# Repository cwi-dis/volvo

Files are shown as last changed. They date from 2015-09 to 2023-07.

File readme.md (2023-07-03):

# Volvo Design Challenge 

This repository contains software and instructions for the exhibit entered into the Volvo Design Challenge 2015 by ByBorre, with help from the CWI DIS group.

Here is a video of Borre Akkersdijk explaining the vision behind it:

[Sublime News - Volvo Design Challenge - ByBorre (YouTube)](https://youtu.be/kw6YL740Hyo)

From May 2017 until June 2023 the exhibit wass on display in the Atrium at CWI. It was dismantled and put into storage, some instructions on re-assembling it if you happen to have the hardware are in [hwsetup/readme.md](hwsetup/readme.md).

Here is an image of the exhibit on display at CWI:

volvo-exhibit-cwi

Contents:

- **hwsetup** contains minimal instructions to revive the piece. See [hwsetup/readme.md](hwsetup/readme.md).

- **production** contains the hardware and software as originall built in 2017:
	- [production/readme.txt](production/readme.txt) has terse instructions on putting everything together.
	- **production/hardware** has the schematics for the matrix touch sensor (for the volume-like pad).
	- **production/jeenode** has software for the three types of JeeNode boards: the receiver, the 4-pad sender and the matrix sender.
	- **production/receiver** has the Python script that communicates with the jeenode receiver.
	- **production/server** has the web server that connects the receiver and the visualisation.
	- There are various scripts here to run everything.
- **artwork** contains the artwork for the visualisation, see [artwork/readme.txt](artwork/readme.txt) for details.
- **jeenode_test** is an Arduino program to test the matrix-style touch interface.
- **photon_experiment** is an earlier touch experiment using a Particle Photon.

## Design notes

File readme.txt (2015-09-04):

Read a lot of pressure sensors using one Particle Photon.

Sensors are in a matrix, with a diode to decould them. See
schematic.jpg for a hardware diagram.

Each row is enabled in turn (using a digital pin pulled to ground),
and then each of the sensors for that row is read (using an analog pin).
Then we advance the row, and when we've read all we store the data in the cloud.
We've seen about 10 sets of 64 readings per second.

sensors2cloud.ino runs on the Photon. Adjust rowPins and
columnPins to the number of sensors.

sensorfromcloud.sh shows how to get the data form the cloud.

You'll need to adapt the device ID and access key.

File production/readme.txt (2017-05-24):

To build the hardware see jeenode/readme.txt and the hardware folder.

To change the visualisation see server/public (which has the HTML files,
SVG files and JavaScripts). For new artwork see ../artwork/readme.txt.

To run the software on a new machine for the first time see server/README.md.

To test things there are scripts runserver.sh, runreceiver.sh and runvisualisation.sh
here, and an overall script run.sh that tries to start everything.

===========================

This set of instructions (in progress) is for using the Raspberry Pi 2.
(Below this section are the old Karnemelk instructions.)

There is an diskimage file for this system, on maunakea, PampusMedia/Special Disk Images.

To assemble the system and configure the display for the first time:

 - Assemble the table, connect the jeenodes, power it up.
 
 - attach the big screen to dispi05 rotated 90 degress (probably clockwise).
 
 - power on dispi05, takes about 60 seconds.
 
 - configure the big display to be portrait mode with the right orientation
   by editing /boot/config.txt and adding
	framebuffer_height=1920
	framebuffer_width=1080
	display_rotate=3
  and possibly removing some NOOBS settings at the end.

 - disable screen blanking. Edit /etc/xdg/lxsession/LXDE/autostart and add
	@xset s noblank 
	@xset s off 
	@xset -dpms
	
 - Install chromium-browser
	
 - Install https://github.com/cwi-dis/igor
 - Install the igor database into ~/.igor, from https://github.com/cwi-dis/igorDatabase.volvo
 
 - Pull in the Mercurial repository for dis/jack
 - Pull in the Mercurial repository for dis/tom
 
 - Install a recent node.js, instructions at 
 	https://nodejs.org/en/download/package-manager/
 	
 - cd volvo/production/server; npm install
 
 - test the server, npm start (or use the script production/runserver.sh)
 
 - test that chromium can connect and display the visualisation,
 	production/runvisualisation.sh
   
 - Attach the JeeNode dongle. Assert it's at /dev/ttyUSB0
 
 - Install <https://github.com/cwi-dis/sensor-relay-py>
 	
 - Run the receiver with runreceiver.sh
 
 - Power down the system (press power button, select "Shut down" in the dialog).

To start the system: NOT UPDATED YET
 
 - Make sure the VGA dongle is connected, VGA is connected and the big screen is on.
 
 - Make sure the JeeNode dongle is connected.
 
 - Turn on karnemelk.
 
 - After about a minute it comes up and tries to start the whole presentation (this
   will take another half minute). If everything works you should see the following things:
   
   - The macbook screen shows a grey pattern
   
   - the JeeNode dongle flashes red LEDs
   
   - the big screen shows the demo
   
 - If anything went wrong (or takes too long) type sequences of CMD-Q, RETURN and CMD-TAB
   until the macbook screen shows the black-and-white desktop again. Then doule-click
   the "start volvo on powerup" icon and hope for the best.
   
 - Always turn of the MacBook BEFORE powering down the display or removing cables. Otherwise
   you may have to go through the "assembly" procedure again.
 
To debug the system:

 - if things don't start up:
   make sure you have connected all dongles and cables. The jeenode dongle should flash when
   it is receiving data from the sensor-jeenodes (and when the receiver progrm is running).
   Looking at the Terminal window (the frontmost is probably the most recent one) may give
   an indication of what is wrong.
   
 - if some of the sensors don't work:
   you scroll down the normal presentation screen (in Google Chrome) there is a "show debug
   console" link. Click this. You will see the output of each individual sensor. You will
   also see an error message in red if any of the jeenodes is not responding.
   
 - if the display is incorrect (wrong screen, wrong orientation):
   - repeat the "assembly" procedure.

===========================

The rest of these instructions are for using karnemelk (the white MacBook)
and the byBorre user (as it has been prepared for the Volvo presentation).

To assemble the system and configure the display for the first time:

 - Assemble the table, connect the jeenodes, power it up.
 
 - attach the VGA dongle and big screen to karnemelk
 
 - power on karnemelk, takes about 60 seconds.
 
 - it may try to start the presentation (some Terminal screens, maybe a
   fullscreen Chrome browser window). Kill everything by using
   CMD-Q (quit application), CMD-TAB (goto next application) and possibly
   NEWLINE (if there is a dialog "are you sure you want to quit")
   until only the Finder is running.
 
 - configure the big display to be portrait mode
   with the right orientation (1080x1920, 75Hz is known to work. If not
   try other refresh frequencies).
   
 - set the big display to be the primary screen.
 
 - Make sure the screen saver/power saver are off (Apple Menu -> System Preferences
   -> Power Saver, all slider to the far right).
   
 - Attach the JeeNode dongle.
 
 - Power down the system (press power button, select "Shut down" in the dialog).

To start the system:
 
 - Make sure the VGA dongle is connected, VGA is connected and the big screen is on.
 
 - Make sure the JeeNode dongle is connected.
 
 - Turn on karnemelk.
 
 - After about a minute it comes up and tries to start the whole presentation (this
   will take another half minute). If everything works you should see the following things:
   
   - The macbook screen shows a grey pattern
   
   - the JeeNode dongle flashes red LEDs
   
   - the big screen shows the demo
   
 - If anything went wrong (or takes too long) type sequences of CMD-Q, RETURN and CMD-TAB
   until the macbook screen shows the black-and-white desktop again. Then doule-click
   the "start volvo on powerup" icon and hope for the best.
   
 - Always turn of the MacBook BEFORE powering down the display or removing cables. Otherwise
   you may have to go through the "assembly" procedure again.
 
To debug the system:

 - if things don't start up:
   make sure you have connected all dongles and cables. The jeenode dongle should flash when
   it is receiving data from the sensor-jeenodes (and when the receiver progrm is running).
   Looking at the Terminal window (the frontmost is probably the most recent one) may give
   an indication of what is wrong.
   
 - if some of the sensors don't work:
   you scroll down the normal presentation screen (in Google Chrome) there is a "show debug
   console" link. Click this. You will see the output of each individual sensor. You will
   also see an error message in red if any of the jeenodes is not responding.
   
 - if the display is incorrect (wrong screen, wrong orientation):
   - repeat the "assembly" procedure.

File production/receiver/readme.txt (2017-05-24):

To be able to run this you must first install sensorrelay from <https://github.com/cwi-dis/sensor-relay-py>.

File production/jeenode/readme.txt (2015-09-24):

FSR_Borre_Reveiver is the software that runs in the jeenode with USB that is connected to the computer.
FSR_Borre_Sender runs on the 3- or 2-sensor tiles.
FSR_Borre_MatrixSender runs on the 9-sensor tile.

For each jeenode, first flash RF12Demo and set node-ID and group-ID, which are kept in EEPROM (and used by our programs).
The receiver should have id 31.

All nodes should be set to group 80. Double-check this, Jack used group 81 for debugging.

After setting id/group flash the correct software and probably label the jeenode.

The normal senders use GND (black) and Vcc (red) on Port 1,
analog inputs on ports 1 (blue), 2 (orange) and 3 (yellow) to the resistor-board.
The resistor board connects to the FSR sensors with color codes blue (1), red (2)
and yellow (3), so using a red wire in stead of the orange (don't ask:-)

The matrix sender uses the resistor/diode board described in ../hardware.

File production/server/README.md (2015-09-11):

## Sensor Relay

Publish-Subscribe architecture on top of WebSockets for relaying sensor data
from sensors to browser clients. Frontend files can be found in the folder
public/.

### Installation

In order to run the server, first make sure you have `node.js` and `npm`
installed. You should be able to get both by installing Node from your
operating system's package manager.

Once you have Node and NPM installed change into the project's root directory
and run the following command:

    $ npm install

This will install all the project's dependencies into the project's root
folder. The server is now ready to run.

### Running the application

To start the application run the following command:

    $ npm start

This will set up a WebSocket server on port 23148 and a HTTP server on
port 8080. Opening `http://localhost:8080` in a web browser will display
the visualisations and any data sent to port 23148.

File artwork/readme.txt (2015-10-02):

To prepare new artwork by Evan (saved as SVG with bitmaps inlined) do the following steps:
- Remove the preamble, everything before the <svg> tag (about 10 lines).
- Insert the content of svg-defs somewhere near the top (inside the first <g> element for example)
- Set the fill pattern of the hand segments correctly by adding
  	style="fill: url(#handfill)"
  to the polygons in group _x3C_hand_x5F_fill_x5F_group_x3E_ (which is
  inside group Hand_x5F_Action)
- Compare the result to ../production/server/public/img/volvo_graphic.svg to double
  check I haven't forgotten anything, there may be a few other IDs that need changing.
- Finally copy the new artwork to ../production/server/public/img/volvo_graphic.svg

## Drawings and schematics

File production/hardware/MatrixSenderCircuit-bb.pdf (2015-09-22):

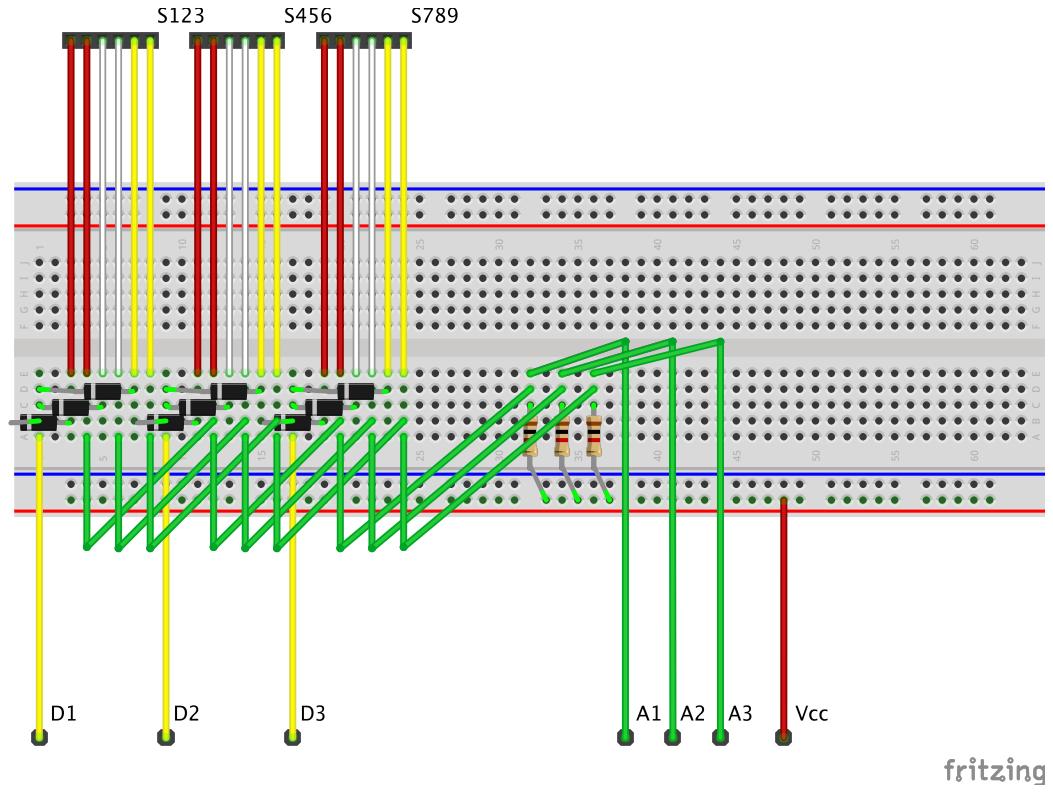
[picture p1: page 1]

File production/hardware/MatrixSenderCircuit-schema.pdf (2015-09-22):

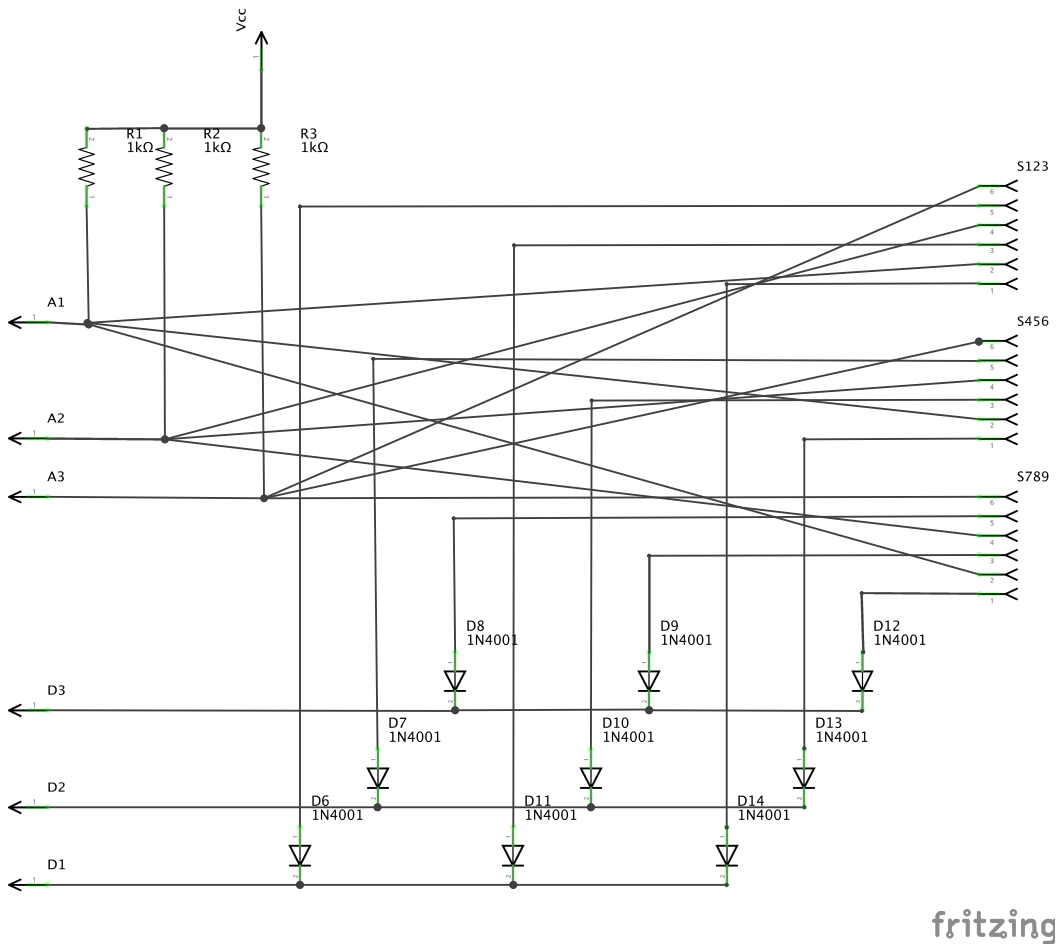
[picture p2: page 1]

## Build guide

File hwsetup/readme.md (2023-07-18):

# Reviving the Volvo hardware

These instructions (and the referenced video) come from <https://github.com/cwi-dis/volvo>, which also contains all the source code to the software, plus some schematics, background information etc.

volvo-exhibit-cwi

## Parts list
 
You should have the following parts before you start:

- The table
- Power supply to the table (5V, 2A, tip positive)
- Raspberry PI 2B
- 16GB Flash card
- Jeenode JeeLink USB 822MHz receiver
- Raspberry PI power supply
- HDMI monitor (preferably portrait orientation)
- Ethernet connection

Here is a quick walkthrough video of the hardware in operation: [VolvoHardwareWalkthrough.mp4](VolvoHardwareWalkthrough.mp4)

(visit the website, above, if you cannot see this video).

## Table reconstruction (old)

The table legs can come off, and the table can be split into three parts. If that has happened you need to put it together again. If the table has been split into three parts you will also need to re-connect to power distribution to all of the sensors boards. Hopefully things have been clearly labeled.

Here is a picture of the table from below. It may give you an idea on how to re-assemble it if you have to do that:

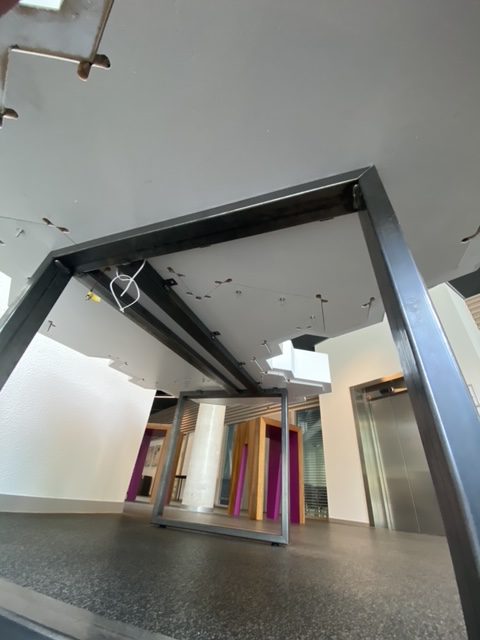
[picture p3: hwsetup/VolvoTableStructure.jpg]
table


Connect the table to its power supply and plug it in. It _may_ be possible to see some of the indicator lights on the sensor boards light up, if you peek under the touch surfaces.

## Table Reconstruction (July 2023)

It turns out we had to take the table apart. Here is a picture of the bits you need to find:

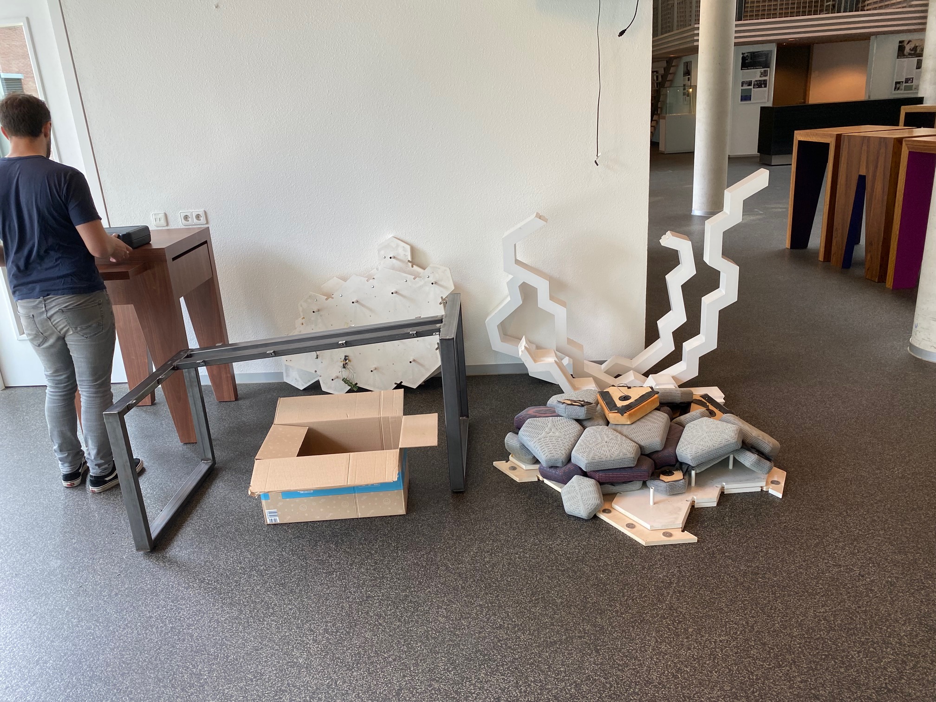
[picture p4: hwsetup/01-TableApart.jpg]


First you need to connect the three parts of the table floor, using the provided bolts. Here is a picture of the first two parts connected. Notice the marker "1" on both the table floor piece and base. You need to align these.

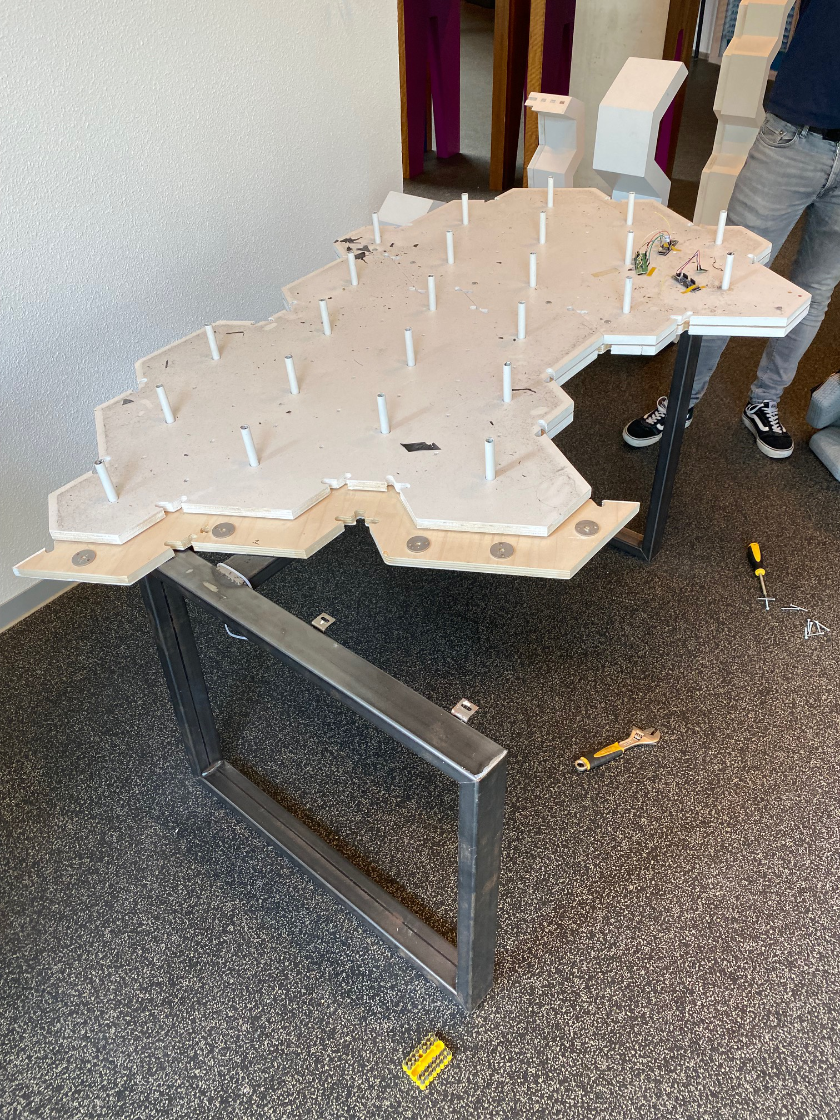
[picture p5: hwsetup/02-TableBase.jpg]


After connecting the third part of the table floor affix it to the base using the screws. Now you can attach the three pieces of the table rim. It should now look like this:

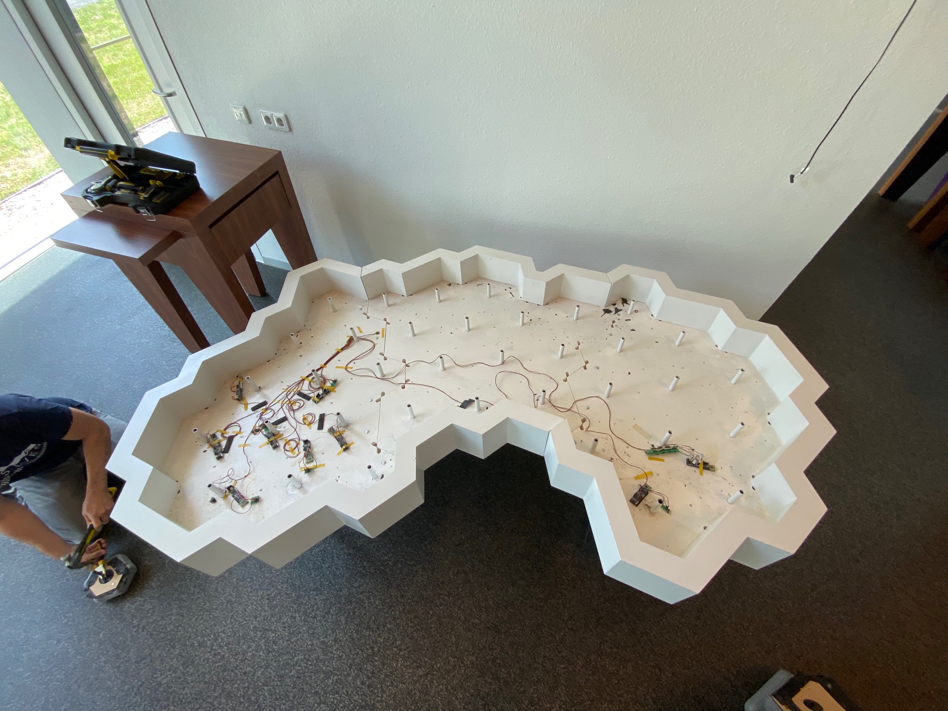
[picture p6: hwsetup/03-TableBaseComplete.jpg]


Connect the power routing. From the central power distribution board there are red/black wires to every sensor controller board. Check the picture above (or one of the ones below) for how to connect.

Next you need to reconstruct the top cover. Lay it upside-down on the floor. Insert all the rods. Start inserting the rods into the table from the middle: the light grey tiles that have no sensors.

Attach the sensors in the tiles to the sensor controller boards. Here is a picture of the volume tile  connection (right side of the table):

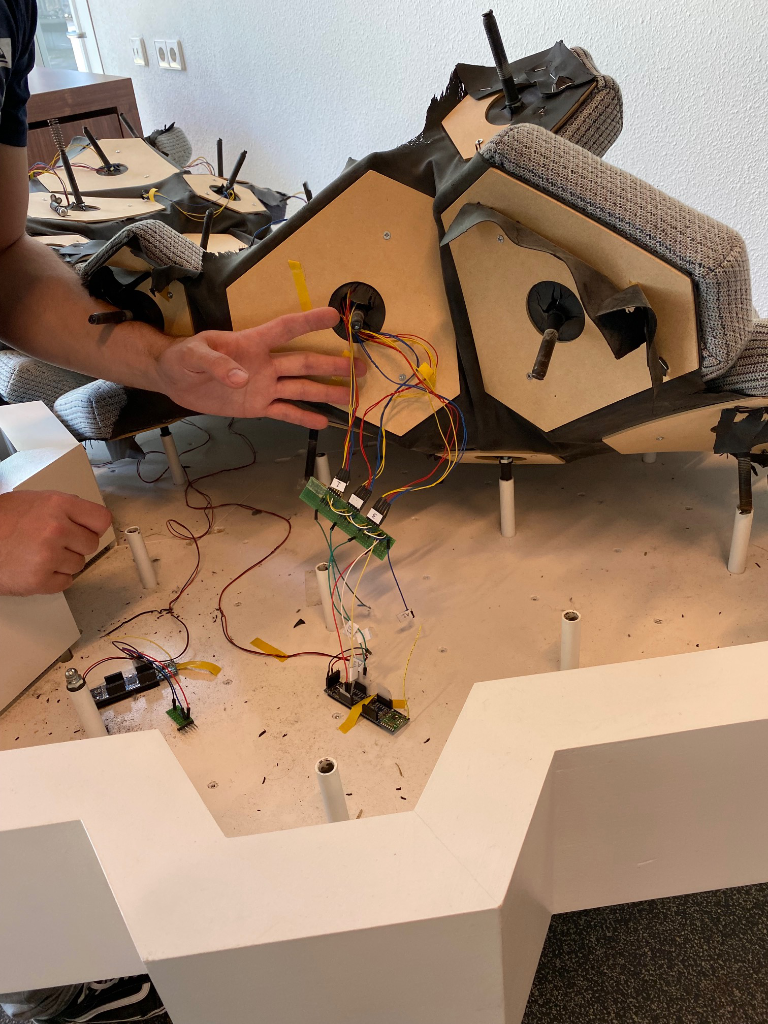
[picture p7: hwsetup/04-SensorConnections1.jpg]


And a picture of the hand tile connection:

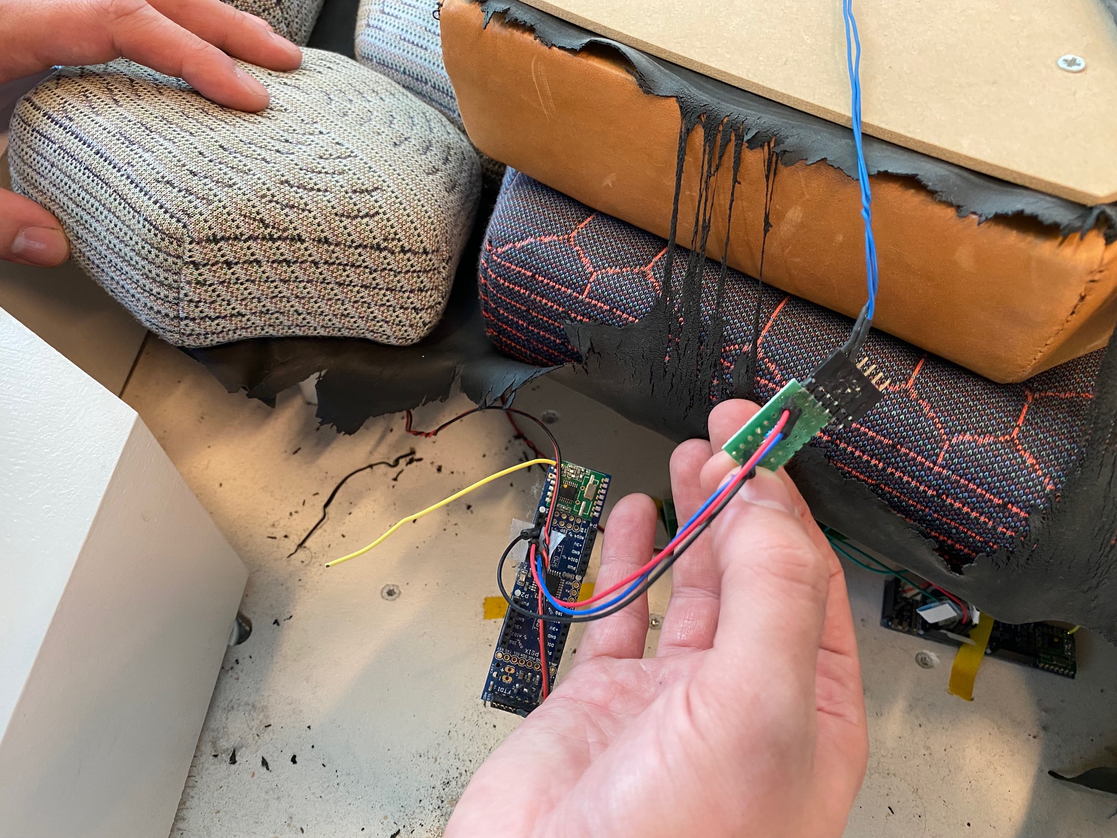
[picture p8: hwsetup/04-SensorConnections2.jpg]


Here is a picture of the sensor tile connections on the left hand side of the table:



There are a number of other pictures in this folder (on github), check them out if things are unclear.

Next connect the power supply and hope for the best.

## Raspberry PI re-creation

If you have all the components listed above: skip this section, try the "putting it all together" section, and just hope it works.

### Re-creating the Flash card

If you have the 16GB Flash card and it works: you should be all set. But the card will probably die in a few years.

If you need to re-create the flash: get a 16GB Flash card and copy the file `rpi2-byBorreVolvo-20230703-image.dd` to it **verbatim**. I.e. do a raw copy.

To get this image: contact the DIS group at Centrum voor Wiskunde & Informatica. It is located on the archival disk `DisArch2021` in `Special Disk Images`.

Something like `dd` to the raw device will work on MacOS or Linux (after you find the correct NNN in the command below, using `diskutil list`). Get a Linux or MacOS geek to help you with these steps.

```
sudo dd if=rpi2-byBorreVolvo-20230703-image.dd of=/dev/rdiskNNN bs=1M
```

### Checking the PI

If you have lost the Raspberry PI get another RPI Model 2B. They are all the same. Insert the card.

Connect the PI to an ethernet. It will show up as `volvo.local`. Login as user `pi`, password `borre`.

### JeeLink

If the JeeLink is lost that is a problem: they are no longer available. You could try contacting the Distributed and Interactive Systems group at Centrum Wiskunde en Informatica to see if they have one lying around.

## Putting it all together

Plug the Jeelink into the PI. Plug the HDMI display into the PI. Plug the Ethernet into the PI. Plug the power supply into the PI. Connect the power supply to an outlet.

The PI and the table communicate wirelessly, and they don't have to be too close to each other, 10 meter should be fine, 100 meter is probably pushing it.

## It does not work

You best bet is to contact the CWI DIS group to see if anyone there can help you. Otherwise: this repository does contain all needed software, source code, hardware shcmatics, etc. But it was never intended to make it easy to find all the information, sorry.

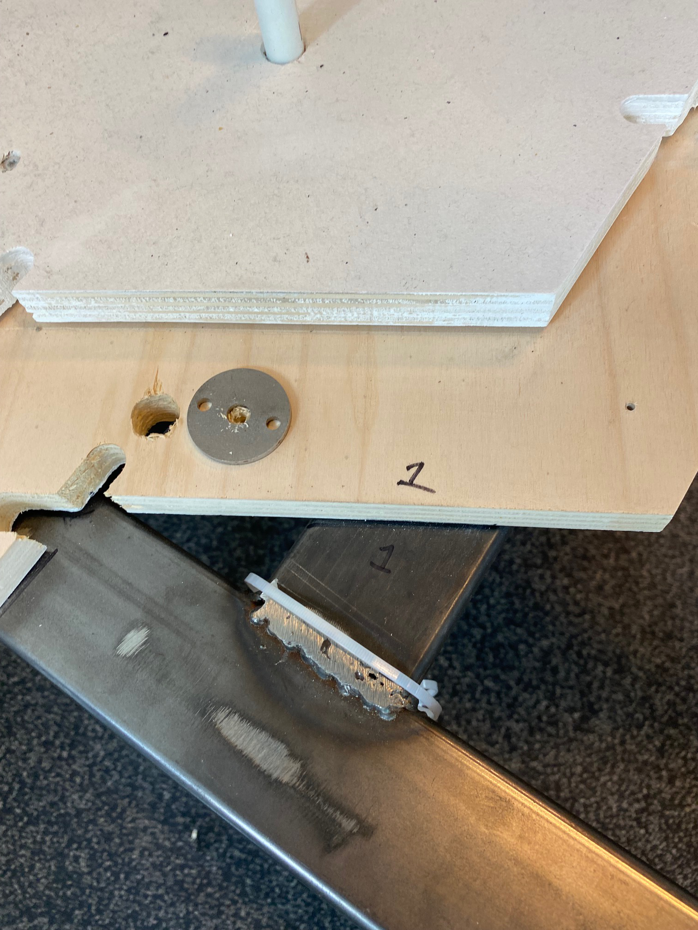
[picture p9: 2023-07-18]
hwsetup/TableAlign.jpg

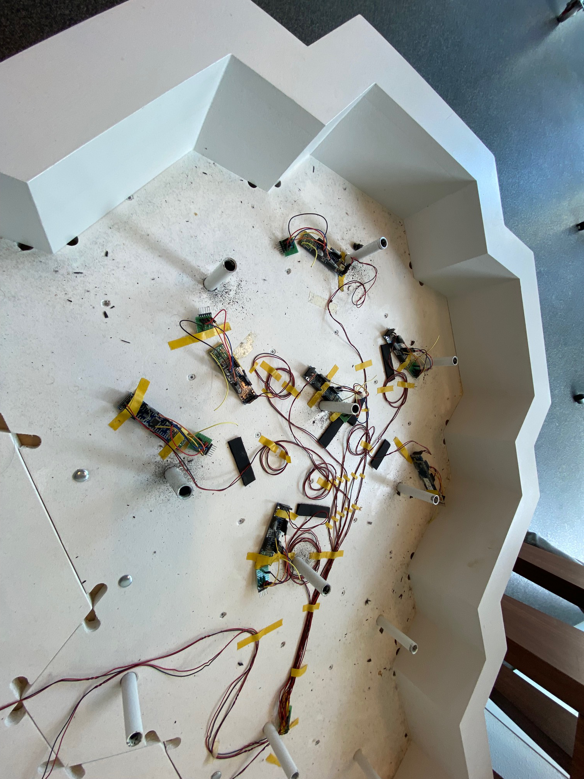
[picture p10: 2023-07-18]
hwsetup/IMG_0018.jpg

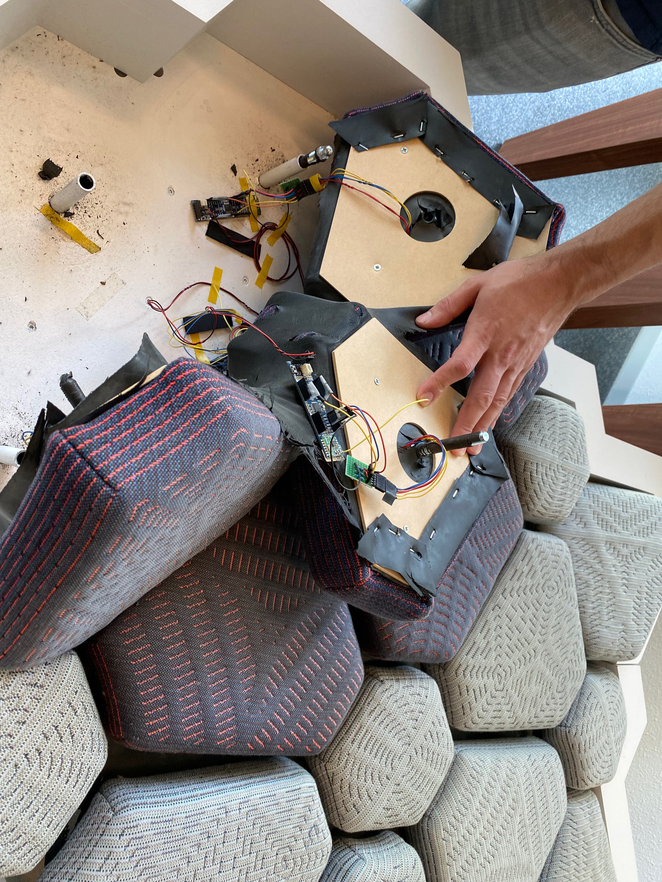
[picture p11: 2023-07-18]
hwsetup/IMG_0007.jpg

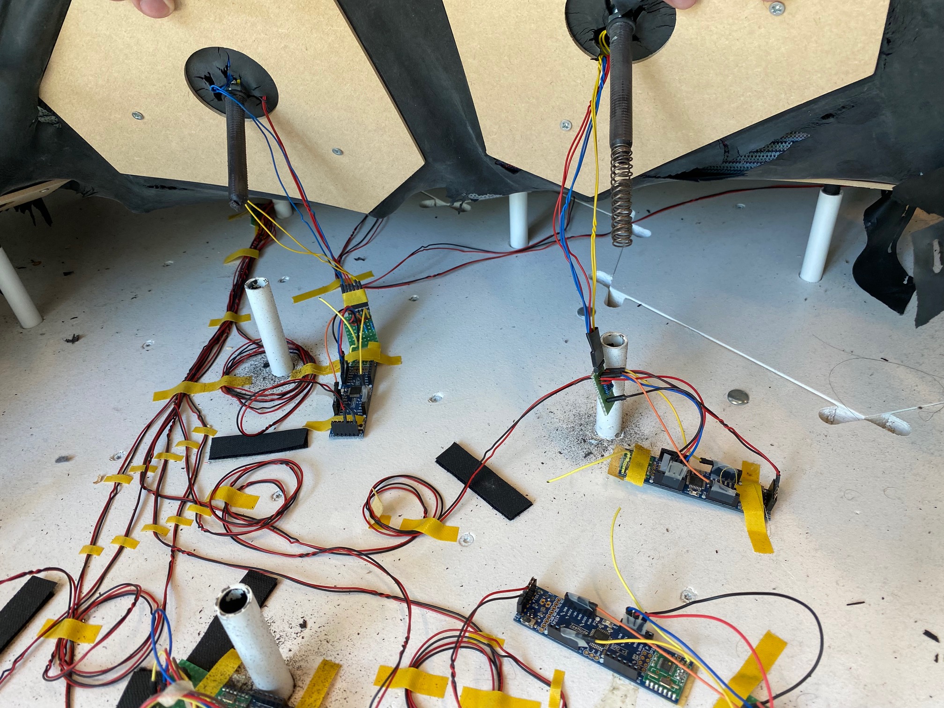
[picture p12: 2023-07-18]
hwsetup/IMG_0012.jpg

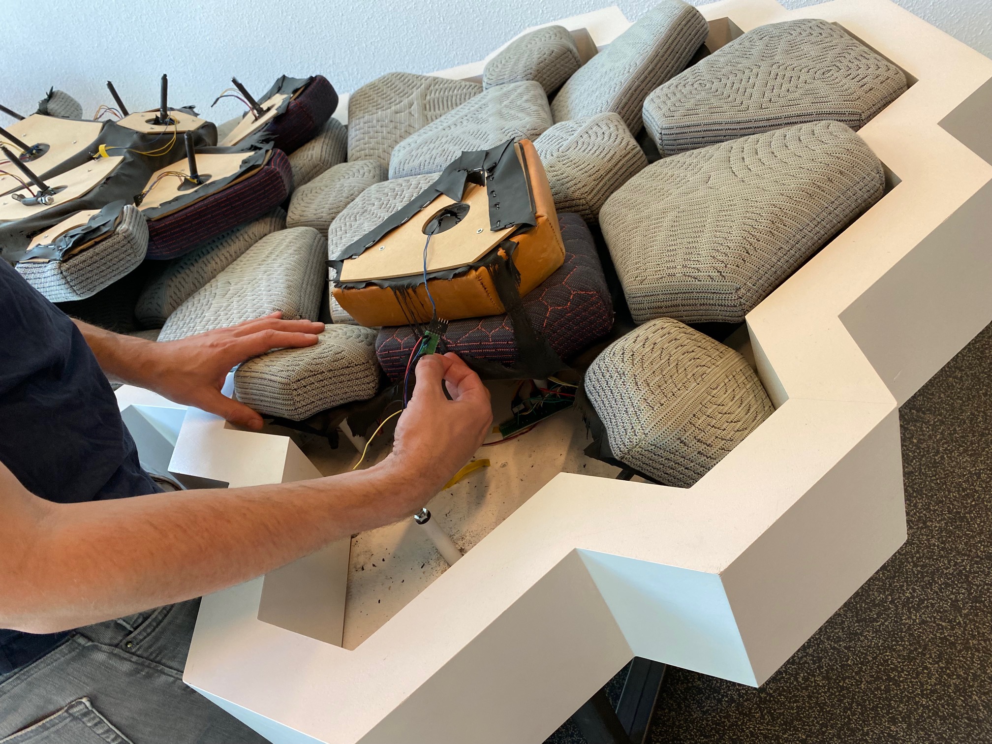
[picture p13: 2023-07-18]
hwsetup/06-AlmostDone.jpg

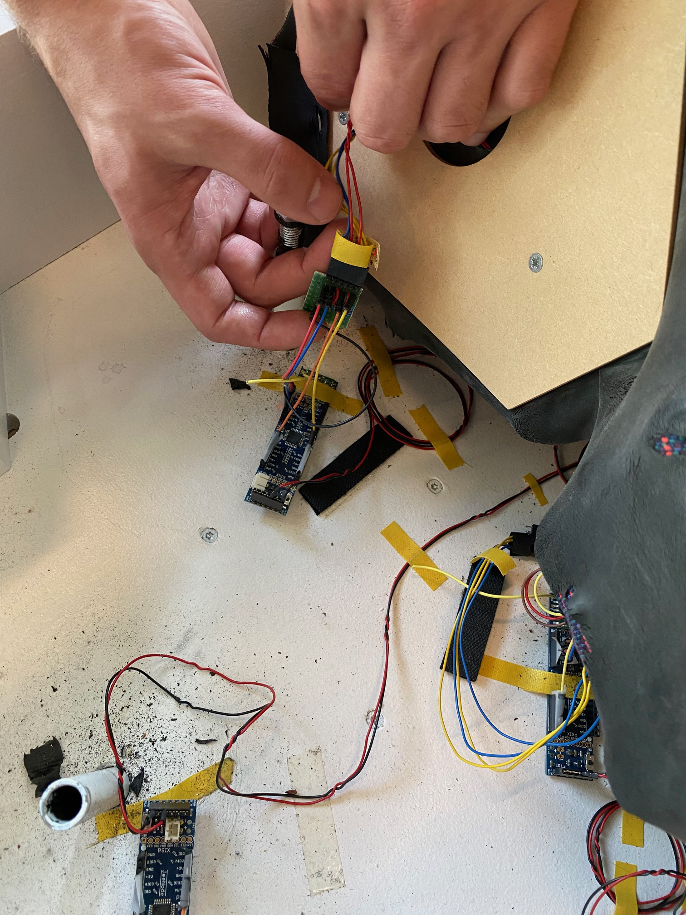
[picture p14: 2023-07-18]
hwsetup/IMG_0009.jpg

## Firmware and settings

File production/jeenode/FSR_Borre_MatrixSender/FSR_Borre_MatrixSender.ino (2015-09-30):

/// @dir pollee
  //This the software we used to upload to the pollee. Each second 5 packets/per second, so that each poller has 5*25*2=250 packets/per second, and this is good for sink node to work.
/// This can run on several nodes, and get data to the central "poller" node.
// 2011-11-23 <jc@wippler.nl> http://opensource.org/licenses/mit-license.php
//
// Warning: this test will flood the radio band so nothing else gets through!
//
// To prepare for this test, you need to upload RF12demo to each pollee first,
// and set its node ID, group (77) and band (868 MHz). Node IDs must be in the 
// range 1 .. NUM_NODES, as defined in poller.ino (all nodes must be present).

#include <JeeLib.h>
#include <Ports.h>
#include <RF12.h>

#define MAGIC 43
#define IFDEBUG if(0)

//
// Power saving features. #undef to disable
//
#define POWERSAVETIMEOUT 10000    // Go to sleep after 10 seconds of no polls received
#define POWERSAVEDURATION 60000   // Go to sleep for 60 seconds
#undef NAP_AFTER_POLL

#ifdef POWERSAVETIMEOUT 
unsigned long lastReceptionTime;

ISR(WDT_vect) { Sleepy::watchdogEvent(); }

#endif

#define NROW 3
#define NCOLUMN 3
#define NPORT 3 /* max(NROW, NCOLUMN) */
#define NSENSOR (NROW*NCOLUMN)

Port ports[] = {
  Port(1),
  Port(2),
  Port(3)
};

typedef struct {
  byte magic;
  byte node;
  byte lowbat;
  byte data[NSENSOR]; 
} Payload;

Payload payload;

void setup () {
  IFDEBUG Serial.begin(57600);
  IFDEBUG Serial.println("MatrixSender started");
  // use the node ID previously stored in EEPROM by RF12demo
  payload.node = rf12_config();
  payload.magic = MAGIC;
  for (Port *p=ports; p < ports+NPORT; p++) {
  	// Set the digital pin to output, initizalize to HIGH
  	p->mode(OUTPUT);
    p->digiWrite(HIGH);
    // Set the analog pin to input, disable pullup
    p->mode2(INPUT);
    p->digiWrite(LOW);
  }
#ifdef POWERSAVETIMEOUT
  lastReceptionTime = millis();
#endif

}

int nextRowToRead = 0;

void readSensors() {
  int row = nextRowToRead++;
  if (nextRowToRead >= NROW) nextRowToRead = 0;
  // Enable this row of sensors
  ports[row].digiWrite(LOW);
  // Not needed? delay(10);
  for (int col=0; col < NCOLUMN; col++) {
  	// It is suggested to discard one analog reading to stabilize
  	// the ADC
    uint16_t value; //  = ports[col].anaRead();
    value = ports[col].anaRead();
    uint8_t newval = (1023-value) >> 2;
    int i = row*NCOLUMN + col;
    if (newval > payload.data[i]) payload.data[i] = newval;
    i++;
    IFDEBUG Serial.print((int)value);
    IFDEBUG Serial.print(' ');
  }
  ports[row].digiWrite(HIGH);
  IFDEBUG Serial.println();
}

void clearSensors() {
  for (int i=0; i<NSENSOR; i++) payload.data[i] = 0;
}

void loop () {
  // wait for an incoming empty packet for us
  if (rf12_recvDone() && rf12_crc == 0 && rf12_len == 0 && RF12_WANTS_ACK) {
    // read battery status
    payload.lowbat = rf12_lowbat();
    IFDEBUG { if (payload.lowbat) Serial.print("LOWBAT "); }
    // read data from the analog pins and store it into the payload struct
#ifdef POWERSAVETIMEOUT
    lastReceptionTime = millis();
#endif
    IFDEBUG Serial.println("poll ");
    // Note that we transmit the data that we collected in the previous loop
    // start transmission
    rf12_sendStart(RF12_ACK_REPLY, &payload, sizeof payload);
    rf12_sendWait(1);   // Wait for transmission completion with CPU in IDLE mode
    clearSensors();
#ifdef NAP_AFTER_POLL
    rf12_sleep(RF12_SLEEP);
    Sleepy::loseSomeTime(NAP_AFTER_POLL);
    rf12_sleep(RF12_WAKEUP);
 #endif 
  }
  else {
#ifdef POWERSAVETIMEOUT
    if (millis() > lastReceptionTime + POWERSAVETIMEOUT) {
      IFDEBUG { Serial.println("Sleep"); delay(10); }
      rf12_sleep(RF12_SLEEP);
      Sleepy::loseSomeTime(POWERSAVEDURATION);
      rf12_sleep(RF12_WAKEUP);
      lastReceptionTime = millis();
      IFDEBUG Serial.println("Wakeup");
    }
#endif
    readSensors();
  }
}

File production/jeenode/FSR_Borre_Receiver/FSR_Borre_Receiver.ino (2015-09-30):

/// @dir poller
/// Polls a number of "pollee" nodes as fast as possible to get data from them.
// 2011-11-23 <jc@wippler.nl> http://opensource.org/licenses/mit-license.php
//
// Warning: this test will flood the radio band so nothing else gets through!
//
// Maximum rates will only be achieved if all nodes 1 .. NUM_NODES are powered
// up, properly configured, and pre-loaded with the pollee.ino sketch.

#include <JeeLib.h>

const byte NUM_NODES = 9; // poll using node ID from 1 to NUM_NODES 

#define MAGIC 43  // Magic number that signals an ACK comes from our sensors

#define POLL_TIMEOUT 20  // How many milliseconds to wait for poll reply
#define MAX_POLL_FREQ 10  // Poll sensors at most 25 times per second
#ifdef MAX_POLL_FREQ
// If the poll frequency is maximised the sensors can powerdown
// after a poll, because they know they will not be polled again for a
// certain time
#define MIN_POLL_INTERVAL (1000/MAX_POLL_FREQ)
uint32_t nextPollCycleTime;
#endif // MAX_POLL_FREQ

#define IFDEBUG if(0)

typedef struct {
  byte magic;
  byte node;
  byte lowbat;
  
  byte data[0]; 
} Payload;

byte nextId;
MilliTimer timer;

void setup () {
  Serial.begin(57600);
  //rf12_initialize(31, RF12_868MHZ, 80);
  rf12_config();
}

void loop () {
  // switch to next node
  if (++nextId > NUM_NODES) {
    nextId = 1;
#ifdef MAX_POLL_FREQ
    // Go to sleep until the next poll cycle can be started
    uint64_t now = millis();
    if (now < nextPollCycleTime) {
      delay(nextPollCycleTime - now);
      now = millis();
    }
    nextPollCycleTime = now+MIN_POLL_INTERVAL;
#endif
  }
    
  // send an empty packet to one specific pollee
  rf12_sendNow(RF12_HDR_ACK | RF12_HDR_DST | nextId, 0, 0);
  // wait up to 10 milliseconds for a reply
  timer.set(POLL_TIMEOUT);
  
  while (!timer.poll()) {
    if (rf12_recvDone() && rf12_crc == 0 && rf12_len > 2) {
      // got a good ACK packet, print out its contents
      const Payload* p = (const Payload*) rf12_data;
      
      Serial.print("{\"n\":"); 
      Serial.print(nextId);
      Serial.print(",");
      if (p->magic != MAGIC || p->node != nextId) {
        Serial.println("\"error\":\"badResponse\"}");
        return;
      }
      int count = rf12_len - sizeof(Payload);
      // calculate base ID

      if (p->lowbat) {
        // Low-battery indicator for this sensor
        Serial.print("\"error\":\"lowBattery\",");
      }
      for(int i=0; i<count; i++) {
        int value = p->data[i];
        Serial.print("\""); Serial.print(i+1); Serial.print("\":"); Serial.print(value);  
        if (i < count-1) Serial.print(",");            
      }
      Serial.println("}");    
      return;
    }
  }
  Serial.print("{\"n\":"); 
  Serial.print(nextId);
  Serial.print(",");
  Serial.println("\"error\":\"noResponse\"}");
 }

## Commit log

2015-09-04 Experiment to read a matrix of pressure sensors
2015-09-07 added HTML sample for reading form the Particle Cloud
2015-09-09 changed structure to play nice with the Arduino IDE
2015-09-09 added script to read data from the serial port and send it to a web socket
2015-09-09 added slightly modified version of the relay server with the tentative visualisation
2015-09-17 Added option to run without pubsub server, and print last time seen on control-C
2015-09-17 Read 9 sensors in matrix configuration
2015-09-20 Implemented optional power saving mode after 10 seconds of inactivity
2015-09-21 Power down the radio during sleep, power usage goes down to 5uA
2015-09-21 Implemented optional maximizing of poll frequency, and in-measurement powerdown in the sensors. Can get operating power use down to 5mA, but currently disabled.
2015-09-22 Circuit for matrix
    [MatrixSenderCircuit.fzz]
2015-09-22 Mod to wire color
    [MatrixSenderCircuit.fzz]
2015-09-22 Reordering files
    [MatrixSenderCircuit.fzz]
2015-09-23 Communicate node/sensor number independently over the serial line, enlarged timeout to 20ms
2015-09-28 Removed preamble of svg, which causes a turd on-screen when inserted into the html page
2015-09-28 Use on/off status of sensors only, and seriously lower the threshold
2015-09-28 Treat swipe area sensors as a whole
2015-09-29 Ignore poll replies not coming from the correct jeenode
    [FSR_Borre_Receiver.ino]
2015-09-29 Return maximum per-sensor value seen since last poll
2015-09-30 Implemented automatic calibration
2015-09-30 Read sensors one row at a time so we don't go deaf for too long
    [FSR_Borre_MatrixSender.ino]
2015-09-30 Lower poll frequency to 10Hz which is smoother (50Hz filled up tty buffers)
2016-03-22 Updated for running on a Raspberry PI 2
2016-05-17 Updated for running on the ground floor
2016-06-14 Use thread to feed the dog
